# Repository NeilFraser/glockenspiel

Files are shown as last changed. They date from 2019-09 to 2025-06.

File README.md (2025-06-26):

# Glockenspiel
Internet-controlled glockenspiel played by a Raspberry Pi.

To use the glockenspiel, visit [neil.fraser.name/hardware/glockenspiel/editor](https://neil.fraser.name/hardware/glockenspiel/editor)

For details about the hardware, visit [neil.fraser.name/hardware/glockenspiel](https://neil.fraser.name/hardware/glockenspiel/)

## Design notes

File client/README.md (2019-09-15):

# Glockenspiel
WiFi-controlled glockenspiel run by a Raspberry Pi.

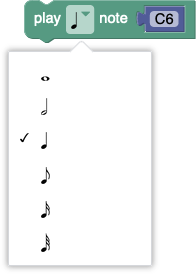
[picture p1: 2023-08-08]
server/html/hardware/glockenspiel/docs/note-lengths.png

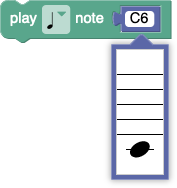
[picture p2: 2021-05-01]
server/html/hardware/glockenspiel/docs/note-pitch.png

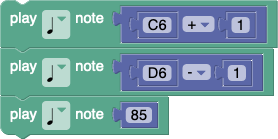
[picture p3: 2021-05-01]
server/html/hardware/glockenspiel/docs/sharp-flat.png

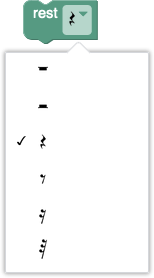
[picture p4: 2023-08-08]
server/html/hardware/glockenspiel/docs/rest-lengths.png

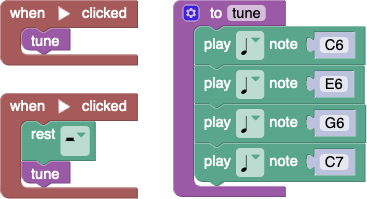
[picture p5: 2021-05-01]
server/html/hardware/glockenspiel/docs/starts.png

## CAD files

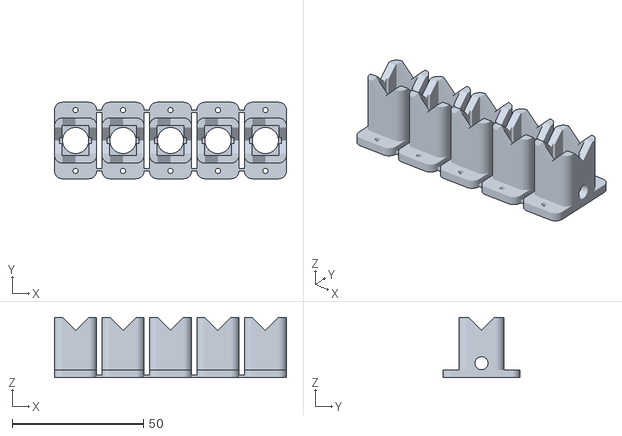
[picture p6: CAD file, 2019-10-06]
hardware/mount-white-5x.stl
88.5 x 29.2 x 23.0

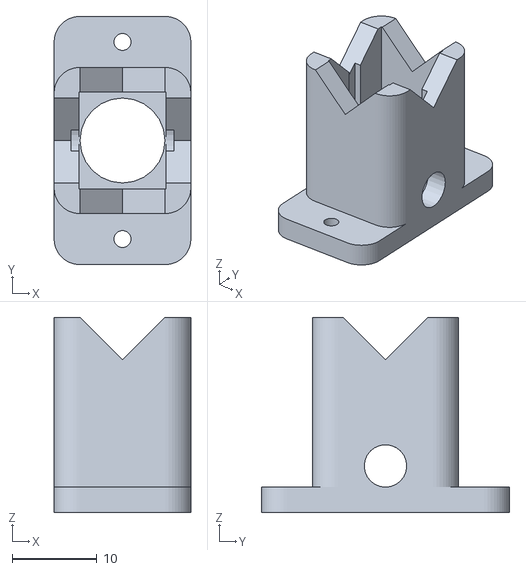
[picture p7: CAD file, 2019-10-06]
hardware/mount-white.stl
16.1 x 29.2 x 23.0

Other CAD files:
hardware/mount-black-5x.stl
hardware/mount-black.stl
hardware/mount-black-5x.skp
hardware/mount-black.skp
hardware/mount-white-5x.skp
hardware/mount-white.skp

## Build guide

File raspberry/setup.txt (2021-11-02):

Setting up the Glockenspiel's Raspberry Pi Zero W from scratch.

Install Raspberry Pi OS Lite on an SD card.
https://www.raspberrypi.org/software/operating-systems/

Switch OFF solenoids using hardware switch.

Boot Raspberry Pi with SD card

Login with: pi / raspberry

To prevent some GPIO pins going high on boot, add this line to /boot/config.txt:
  gpio=2-27=op,dl

> sudo raspi-config
- Configure Wifi
- Hostname (glockenspiel)
- Autologin (yes)
- Timezone
- Reboot

Switch ON solenoids using hardware switch.

Set up any alternate wifi in /etc/wpa_supplicant/wpa_supplicant.conf
More info: https://www.raspberrypi.org/documentation/configuration/wireless/wireless-cli.md

Install pigpio:
> sudo apt-get install pigpiod
> sudo apt-get install python3-pigpio

Download the glockenspiel files:
> wget -O - https://tinyurl.com/glockenspiel-setup | bash
That's -O (Oh), not -0 (zero).
That's an alias to https://raw.githubusercontent.com/NeilFraser/glockenspiel/master/raspberry/update.sh

To start the player automatically, add these lines to /etc/rc.local:
  sudo pigpiod
  /usr/bin/python3 /home/pi/player.py &

Start the Westminster Quarters with this:
> crontab crontab.txt

Restart
> reboot

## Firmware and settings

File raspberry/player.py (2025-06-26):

#!/usr/bin/python3
"""
Copyright 2019 Neil Fraser

Licensed under the Apache License, Version 2.0 (the "License");
you may not use this file except in compliance with the License.
You may obtain a copy of the License at

  http://www.apache.org/licenses/LICENSE-2.0

Unless required by applicable law or agreed to in writing, software
distributed under the License is distributed on an "AS IS" BASIS,
WITHOUT WARRANTIES OR CONDITIONS OF ANY KIND, either express or implied.
See the License for the specific language governing permissions and
limitations under the License.
"""

"""Fetch tune from server, and play it.
"""

import json
import pigpio
import signal
import sys
import threading
import time
import requests

FETCH_URL = "https://neil.fraser.name/scripts/glockenspiel/fetch.py"

# Strike time for hammer in seconds.
STRIKE_TIME = 8 / 1000.0

# Map of MIDI note values to GPIO pin number.
PINOUT = {
  81:  24,  # A5
  82:  15,  # Bb5
  83:  10,  # B5
  84:  9,   # C6
  85:  14,  # Db6
  86:  25,  # D6
  87:  4,   # Eb6
  88:  11,  # E6
  89:  8,   # F6
  90:  3,   # Gb6
  91:  7,   # G6
  92:  2,   # Ab6
  93:  5,   # A6
  94:  23,  # Bb6
  95:  6,   # B6
  96:  12,  # C7
  97:  22,  # Db7
  98:  13,  # D7
  99:  27,  # Eb7
  100: 19,  # E7
  101: 16,  # F7
  102: 17,  # Gb7
  103: 26,  # G7
  104: 18,  # Ab7
  105: 20   # A7
}

# GPIO pin number of reset button/LED.
RESET_PIN = 21

# Global variable used to pass parsed JSON from the fetch loop
# to the play thread.
new_data = None


class PlayForever(threading.Thread):
  """
  Runs in a separate thread.
  """
  def __init__(self):
    threading.Thread.__init__(self)
    self.pi = pigpio.pi()
    for pinNumber in PINOUT.values():
      self.pi.set_mode(pinNumber, pigpio.OUTPUT)
      self.pi.write(pinNumber, 0)
    self.pi.set_mode(RESET_PIN, pigpio.OUTPUT)
    signal.signal(signal.SIGINT, self.shutdown)

  def run(self):
    global new_data
    stream = None
    stream_index = 0
    pause_remaining = 0
    while(True):
      if new_data:
        if stream:
          print("Interrupting current tune.\n")
          # Insert a pause between the old tune and the new one.
          time.sleep(1)

        print("Got new tune: %s\n" % new_data)
        # Convert tempo from referencing 1/4 note to referencing 1/32 note.
        tempo = (new_data["tempo"] / 8.0) / 1000.0
        stream = new_data["stream"]
        new_data = None
        stream_index = 0
        pause_remaining = 0

        # Number of 1/32nds notes since the start.
        clock32nds = 0
        # Time of start of execution in seconds.
        startTime = time.time()
        # Turn on the reset LED.
        self.pi.set_mode(RESET_PIN, pigpio.OUTPUT)
        self.pi.write(RESET_PIN, 1)

      if stream and stream_index >= len(stream):
        # Turn off the reset LED.
        self.pi.write(RESET_PIN, 0)
        print("Finished playing tune.  Waiting for next tune.\n")
        stream = None

      if stream == None:
        # Just waiting for next tune to arrive.
        time.sleep(1)
        continue

      # Switch the reset GPIO pin from LED to button for a moment.
      # If pressed, terminate the tune.
      self.pi.set_mode(RESET_PIN, pigpio.INPUT)
      if self.pi.read(RESET_PIN):
        print("Tune manually terminated with local reset button.\n")
        stream = None
        continue
      self.pi.set_mode(RESET_PIN, pigpio.OUTPUT)

      if pause_remaining > 0:
        # Keep waiting for the right time for the next note.
        pause_remaining -= 1
        clock32nds += 1
        s = (startTime + clock32nds * tempo) - time.time()
        if (s > 0):
          time.sleep(s)
        continue

      # Read the next item off the stream.
      datum = stream[stream_index]
      stream_index += 1

      if type(datum) == float:
        # New pause.
        pause_remaining = datum * 32
      elif type(datum) == list:
        for note in datum:
          if note in PINOUT:
            self.pi.write(PINOUT[note], 1)
          else:
            print("Skipping invalid note: %s\n" % note)
        time.sleep(STRIKE_TIME)
        for note in datum:
          if note in PINOUT:
            self.pi.write(PINOUT[note], 0)

  def shutdown(self, sig, frame):
    # Gracefully shutdown without spewing traceback.
    # Turn off any powered solenoids.
    print("Shutting down.\n")
    for pinNumber in PINOUT.values():
      self.pi.write(pinNumber, 0)
    self.pi.set_mode(RESET_PIN, pigpio.OUTPUT)
    self.pi.write(RESET_PIN, 0)
    sys.exit(0)


def startup():
  # On start up, play the entire scale.
  global new_data
  stream = []
  for midi in PINOUT.keys():
    stream.append([midi])
    stream.append(1/4)
  new_data = {"tempo": 125, "stream": stream}
  time.sleep(5)


def fetch():
  # Check to see if there's a new tune waiting on server.
  # Return True if successfully connected, false if network fail.
  global new_data, last_status_time
  try:
    text = requests.get(FETCH_URL, timeout=60).text
  except Exception as e:
    print("Failure to fetch: %s\n" % e)
    last_status_time = time.time()
    return False
  if text.strip():
    try:
      unvalidated_data = json.loads(text)
      new_data = validateData(unvalidated_data)
      last_status_time = time.time()
    except Exception as e:
      print("Invalid JSON: %s\n" % e)
      last_status_time = time.time()
      return False
  elif last_status_time + 60 < time.time():
    # Print an "I'm still alive" message once a minute.
    last_status_time = time.time()
    print("Still waiting for next tune.\n")
  return True
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

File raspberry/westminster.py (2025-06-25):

#!/usr/bin/python3
"""
Copyright 2021 Neil Fraser

Licensed under the Apache License, Version 2.0 (the "License");
you may not use this file except in compliance with the License.
You may obtain a copy of the License at

  http://www.apache.org/licenses/LICENSE-2.0

Unless required by applicable law or agreed to in writing, software
distributed under the License is distributed on an "AS IS" BASIS,
WITHOUT WARRANTIES OR CONDITIONS OF ANY KIND, either express or implied.
See the License for the specific language governing permissions and
limitations under the License.
"""

"""Compose the Westminster Quarters for the current time, and send to server.
"""

import json
import requests
from datetime import datetime
from time import sleep

# Server submission page.
SUBMIT_URL = "https://neil.fraser.name/scripts/glockenspiel/submit.py"

# Larger tempo is slower.
TEMPO = 512

# Number of seconds before the minute to submit the chimes.
LAG = 5

# Look up the nearest quarter and hour.
now = datetime.now()
hour = now.hour
quarter_float = now.minute / 15.0
quarter = int(round(quarter_float))
if quarter == 4:
  hour += 1
elif quarter == 0:
  quarter = 4
if hour > 12:
  hour -= 12
if hour == 0:
  hour = 12
print("Hour: %d Quarter: %d" % (hour, quarter))

group1 = [[92], 0.25, [90], 0.25, [88], 0.25, [83], 0.5]
group2 = [[88], 0.25, [92], 0.25, [90], 0.25, [83], 0.5]
group3 = [[88], 0.25, [90], 0.25, [92], 0.25, [88], 0.5]
group4 = [[92], 0.25, [88], 0.25, [90], 0.25, [83], 0.5]
group5 = [[83], 0.25, [90], 0.25, [92], 0.25, [88], 0.5]

# Assemble the notes.
if quarter == 1:
  stream = group1
elif quarter == 2:
  stream = group2 + group3
elif quarter == 3:
  stream = group4 + group5 + group1
elif quarter == 4:
  stream = group2 + group3 + group4 + group5
  # Append the hour bongs.
  for i in range(hour):
    stream.append(1)
    stream.append([88])

data = json.dumps({"tempo": TEMPO, "stream": stream})

# Wait for the right moment.
now = datetime.now()
delay = -LAG - now.second
while delay < 0:
  delay += 60
print("Waiting %d seconds..." % delay)
sleep(delay)

# Transmit the notes to the server.
x = requests.post(SUBMIT_URL, data = {"data": data})
print(x.text)

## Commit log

2019-09-18 Code reorganization
    Move everything to ‘client’ directory (to make room for others, like 3D CAD files).
    Move all downloaded code to ‘third-party’ directory.
    Change FieldPitch to use C6-A7 and MIDI values.
2019-10-02 Visualization updates
    Add flats, add ’15’ octave marker, flip high notes, add additional ledger lines, remove block IDs from JS.
2019-10-06 Add hardware files
    2D laser-cut patterns and 3D printed models.
    [mount-black-5x.skp, mount-black-5x.stl, mount-black.skp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]
2019-10-07 Change 3D model colours to white and black.
    [mount-black-5x.skp, mount-black.skp, mount-white-5x.skp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]
2019-10-07 Add dynamic multi-threading.
2019-10-08 Switch from Memcache to Datastore
2019-10-09 Initial version of raspberry player.
2019-10-11 Don’t cache log writes.
2019-10-19 Remove ES6 keywords.
    JS Interpreter doesn’t support them.
2019-10-30 Switch to whitelist (shorter)
2020-02-03 ‘Upgrade’ from Python 2.7 to Python 3.7
    Python is a non-issue. But App Engine took the opportunity to change everything.
2021-04-27 Enable reset button.
2021-04-27 Disable button
    It tests high all the time for some reason.
2021-04-27 Enable the button.
    It is just reversed.
    [player.py]
2021-04-27 Add shutdown code.
    Disable button again (switching input/outupt mode takes too long).
    [player.py]
2021-04-27 Switch from gipozero to pigpio
    Should be faster?
2021-04-27 Fix reset LED.
    Wrong pin variable
    [player.py]
2021-04-28 Fix broken sanity checking
    [player.py]
2021-04-28 Print current notes, not previous one.
2021-05-01 Move tempo into a named property
    Using the zeroeth entry in the array was hacky and doesn’t allow other meta data in the future.
    [player.py, westminster.py]
2021-06-02 Corrections for new stream format.
    [player.py]
2021-06-02 Fix pause before hour bongs.
    [westminster.py]
2021-06-26 Improve accuracy of westminster quarters
    There’s a lot of variation in when the chimes play, possibly due to crontab or Python runtime loading. To improve punctuality, run the script a minute in advance, assemble the tune, then wait for the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
2021-07-12 Don’t reopen dialogs with space key.
    Closing a dialog with ‘space’ in Firefox would instanly reopen it again. In Chrome a second space would reopen it.
2021-07-22 Handle dialog launch button blur centrally
2023-07-16 Basic framework for MIDI parsing.
    Loads a MIDI file, parses it. Does nothing (yet).
    Commented out for now.
2023-08-06 Fix context error that appeared in App Engine
    3rd party dependencies will bite you every time.
    [player.py]
2023-08-18 Support more types of MIDI files.
    Some MIDI files of type 1 will have notes in track 0.
2023-08-20 Support setTimeout/setInterval in threads.
    Previously it would claim that the thread was running slowly and busy-wait all 10,000 ticks for the task to resume.
2023-08-22 Terminate all threads if one crashes.
2025-06-26 Fix GET/POST escaping of spaces. Terminate daemon if server is unreachable on startup. Recompile.
    [player.py]
2025-06-26 Fix startup and file save.
    [player.py]
